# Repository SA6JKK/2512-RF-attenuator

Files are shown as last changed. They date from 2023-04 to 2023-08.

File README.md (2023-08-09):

# 2512-attenuator
RF-attenuator from 1W 2512 size resistors with both BNC and SMA connectors. Works OK from DC to 30MHz. 

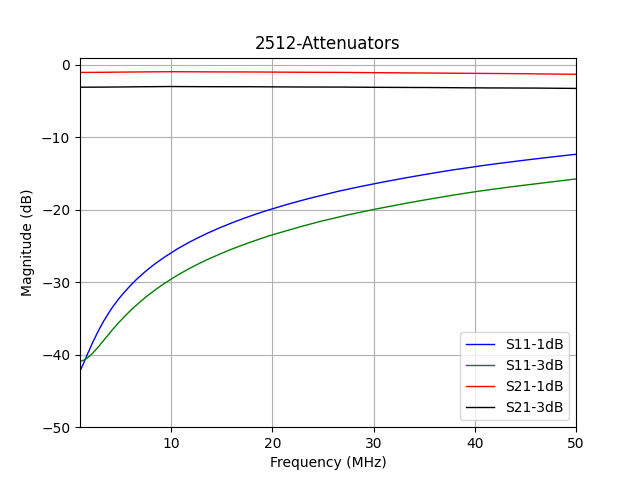
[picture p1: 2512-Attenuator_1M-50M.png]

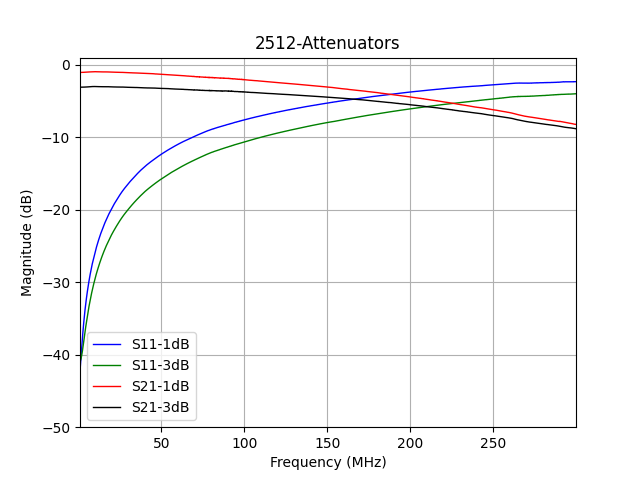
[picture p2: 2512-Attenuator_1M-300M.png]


Measured with NanoVNA-H4 using NanoVNA saver.

---

## PCB Specs

PCB size: 71.5 x  25 x 1.6 mm

PCB Stackup: Two layer FR-4 (No impedance control) 

Traces are not 50 ohm as this is mainly for < 50 MHz use and the size of the entire PCB is thus significantly smaller than the wavelength at this frequency. 

I tried to only use resistors from the E12 series as much as possible.

Two parallel resistors are used for each position for increased thermal handling and to achieve a resistance closer to the calculated values.

---

## Heat Sink

Made to fit the following heat sink. 

> Heat Sink, 4.4 °C/W, TO-218, TO-220, TO-247, 42 mm, 38.1 mm, 25 mm

> Farnell Order code 1710612

---

## Design Notes

* Schematic is in the `plots` folder.
* [Link to RF Attenuator calculator](https://leleivre.com/rf_pipad.html)
* [Link to Parallel Resistor calculator](https://jansson.us/resistors.html)

Connections:
* `R1//R2//R3//R4` (input side, to ground)
* `R5//R6` (top of Pi network)
* `R7//R8//R9//R10` (output side, to ground)

---

## Resistor Values for Various Attenuators

| Resistor | Value for 1dB Attenuator | Value for 2dB Attenuator | Value for 3dB Attenuator | Value for 6dB Attenuator | Value for 10dB Attenuator | Value for 30dB Attenuator |
|---|---|---|---|---|---|---|
| R1 | DNI | DNI | DNI | DNI | DNI | DNI |
| R2 | 2k2 | 820 | 560 | 270 | 180 | 100 |
| R3 | DNI | DNI | DNI | DNI | DNI | DNI |
| R4 | 1k5 | 1k | 560 | 330 | 220 | 120 |
| R5 | 12 | 22 | 33 | 68 | 150 | 1.5k |
| R6 | 10 | 24 | 39 | 82 | 150 | 1.8k |
| R7 | 2k2 | 1k | 560 | 270 | 180 | 100 |
| R8 | 1k5 | 820 | 560 | 330 | 220 | 120 |
| R9 | DNI | DNI | DNI | DNI | DNI | DNI |
| R10 | DNI | DNI | DNI | DNI | DNI | DNI |

DNI = Do Not Install

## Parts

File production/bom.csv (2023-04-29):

Designator | Footprint | Quantity | Value | LCSC Part #
H1 | MountingHole_3.2mm_M3_Pad_Via | 1 | MountingHole_Pad
J1, J2 | BNC_Amphenol_B6252HB-NPP3G-50_Horizontal | 2 | Conn_Coaxial
J3, J4 | SMA_Amphenol_901-143_Horizontal | 2 | Conn_Coaxial
R1, R10, R2, R3, R4, R5, R6, R7, R8, R9 | 2512 | 10 | R

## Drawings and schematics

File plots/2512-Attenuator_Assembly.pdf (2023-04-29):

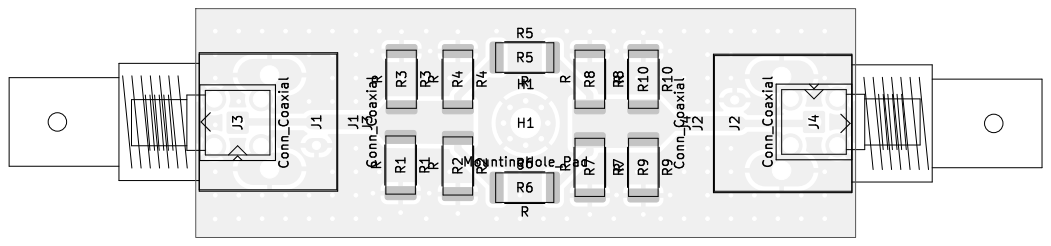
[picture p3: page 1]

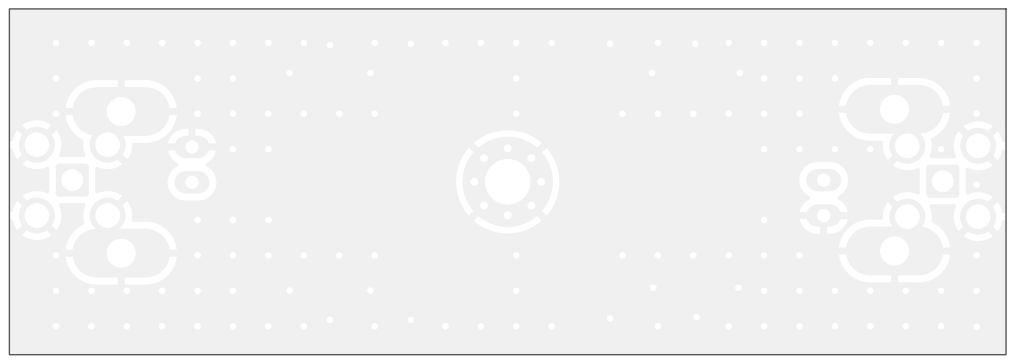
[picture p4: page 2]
D Date: KiCad; kicad; 7.0.1 Size: A4; Rev:

Id: 1/1 Title: File: 2512-Attenuator.kicad_pcb Sheet:

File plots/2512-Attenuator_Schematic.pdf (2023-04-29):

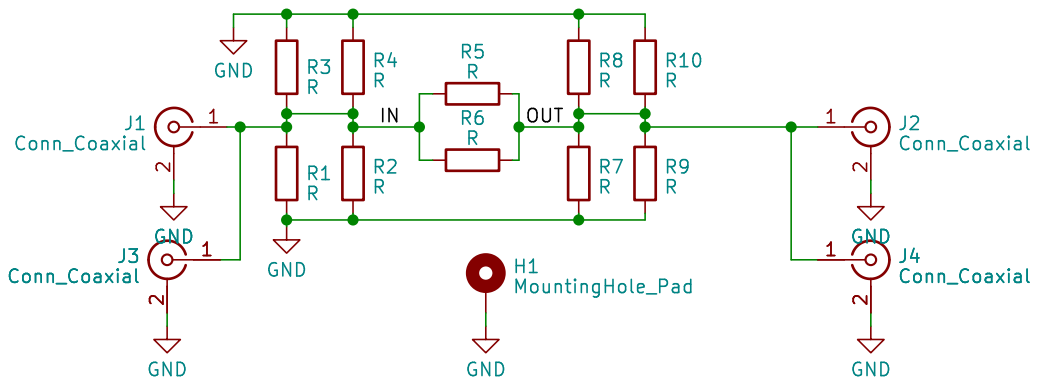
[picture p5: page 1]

Id: 1/1 Title: File: 2512-Attenuator.kicad_sch Sheet: /

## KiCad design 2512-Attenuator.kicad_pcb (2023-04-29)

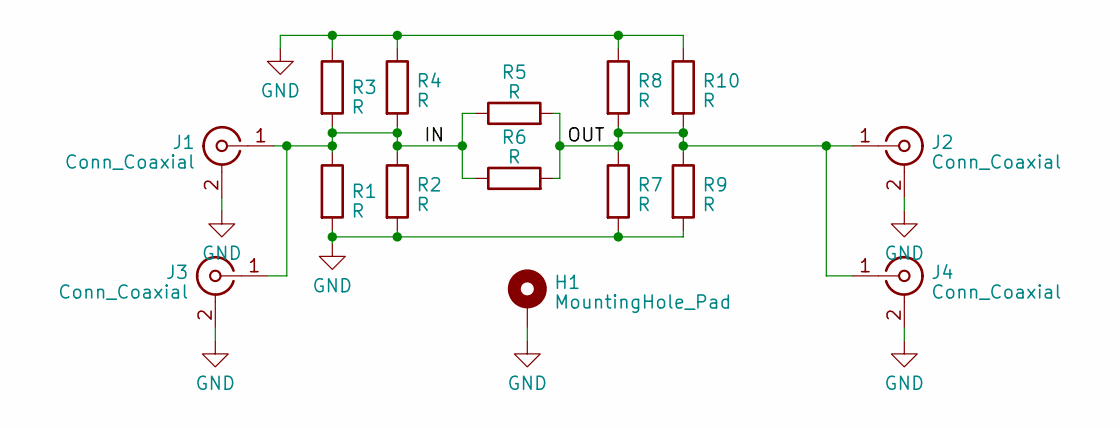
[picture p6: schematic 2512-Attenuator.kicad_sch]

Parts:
H1: MountingHole_Pad; MountingHole_3.2mm_M3_Pad_Via
J1, J2: Conn_Coaxial; BNC_Amphenol_B6252HB-NPP3G-50_Horizontal
J3, J4: Conn_Coaxial; SMA_Amphenol_901-143_Horizontal
R1, R2, R3, R4, R5, R6, R7, R8, R9, R10: R; R_2512_6332Metric_Pad1.40x3.35mm_HandSolder

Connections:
/IN: J1.1 (In), J3.1 (In), R1.1, R2.1, R3.2, R4.2, R5.1, R6.1
/OUT: J2.1 (In), J4.1 (In), R5.2, R6.2, R7.1, R8.2, R9.1, R10.2
GND: H1.1, J1.2 (Ext), J2.2 (Ext), J3.2 (Ext), J4.2 (Ext), R1.2, R2.2, R3.1, R4.1, R7.2, R8.1, R9.2, R10.1

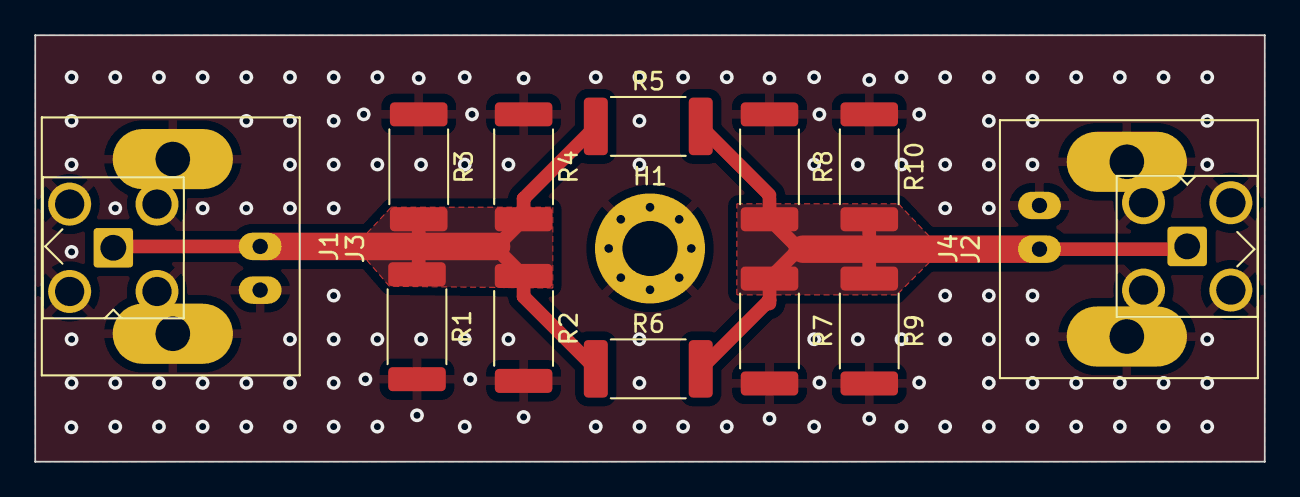
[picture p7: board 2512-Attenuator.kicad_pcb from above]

Board: 2 copper layers, 71.5 x 24.8 mm, 15 parts (0 on the bottom side), 3 nets.

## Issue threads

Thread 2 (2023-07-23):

Request: Add a note about the production stackup for impedance control

DeflateAwning, 2023-07-23:
Should this board be made on a 1.6mm FR4 board? Is it only 4 layers for proper impedance control? Or does it use a different stackup? This info would be great in the README. Thanks!

SA6JKK, 2023-07-24:
I updated the readme with PCB and stackup information

DeflateAwning, 2023-07-24:
Awesome, thank you!

Closed 2023-07-24.

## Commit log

2023-04-29 Add KiCad Files
    Schematic, layout, plots and JLC-PCB production files
    [2512-Attenuator.kicad_pcb, 2512-Attenuator.kicad_sch, bom.csv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]
2023-04-29 Added BoM for 1,2,3,6,10 dB attenuation
2023-07-24 Update README.md with PCB info
    Adds more PCB info and link to attenuator calculator
2023-08-09 Convert resistor values to table
2023-08-09 Updated 30 dB attenuator resistor values
    30 dB attenuation require around 53 ohm to GND and 790 ohm in series. Earlier commit had this opposite way around.
    Parallel resistors for 30 dB changed to be have resistance values closer together to better distribute the heat generated in them.
